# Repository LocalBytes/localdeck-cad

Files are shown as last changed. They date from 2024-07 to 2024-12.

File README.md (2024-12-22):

# LocalDeck CAD

## About

This is the repo for the LocalDeck CAD; it is split into multiple parts:

- [freecad](./freecad)
    - Uses FreeCAD v1
    - Contains all of the mechanical CAD resources
    - You should start with [asm-localdeck](./freecad/asm-localdeck.FCStd)
- [kicad](./kicad)
    - Uses Kicad v8
    - Contains all of the electrical CAD resources

## Contributing

The best way to contribute to the LocalDeck (and it's configurator) is by using the development version in your HomeAssistant, and reporting any issues you find.
Additionally, we would appreciate it if you were to be active on the Forum should we solicit feedback on a new feature or change.

We do not recommend pull-requests to this repo. Git doesn't handle CAD files too well.
If you are a mechanical or electrical engineer, the best way to contribute would be by opening 
If you are a developer, you can also contribute by submitting a pull request to this repository. Please be aware that any code contributed will become the property of Allport-IT LTD.

## Licence
This project is currently published with no specific licence:
- This program is distributed in the hope that it will be useful,
  but WITHOUT ANY WARRANTY
- As an individual user, you are free learn from it, and use it in your own projects
- You must not claim it as your own

Unless otherwise stated, all code is &copy; Allport-IT LTD. All rights reserved.  
"LocalBytes" and the LocalBytes Logo are &reg; of Allport-IT LTD.

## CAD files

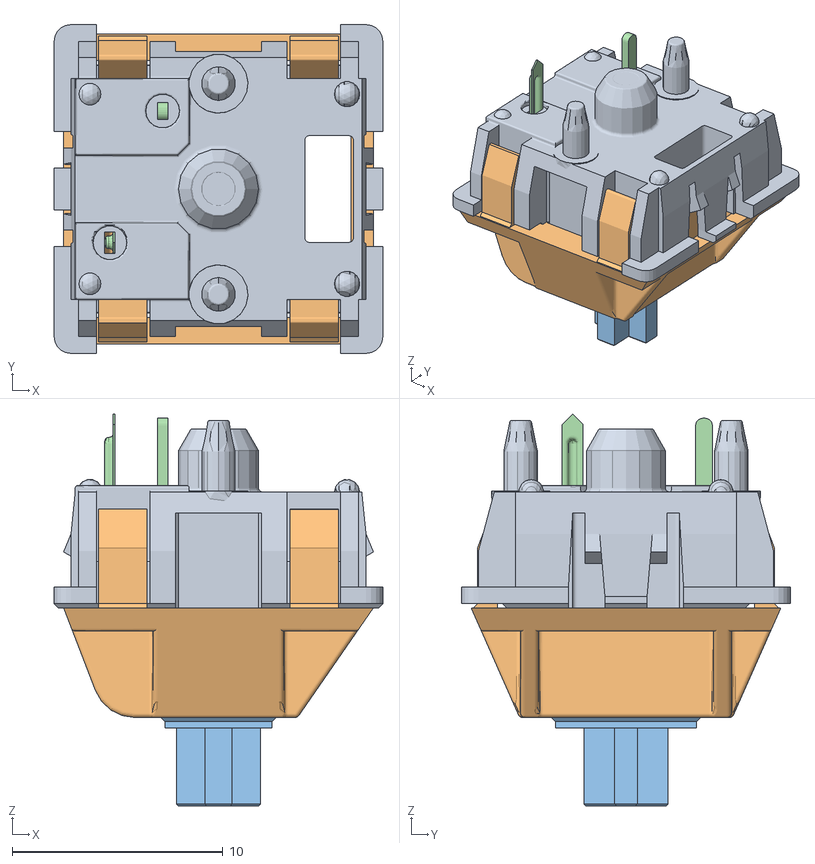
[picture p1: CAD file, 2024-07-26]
freecad/parts/subparts/asm_mx_asm_PCB.obj
15.6 x 15.6 x 18.6

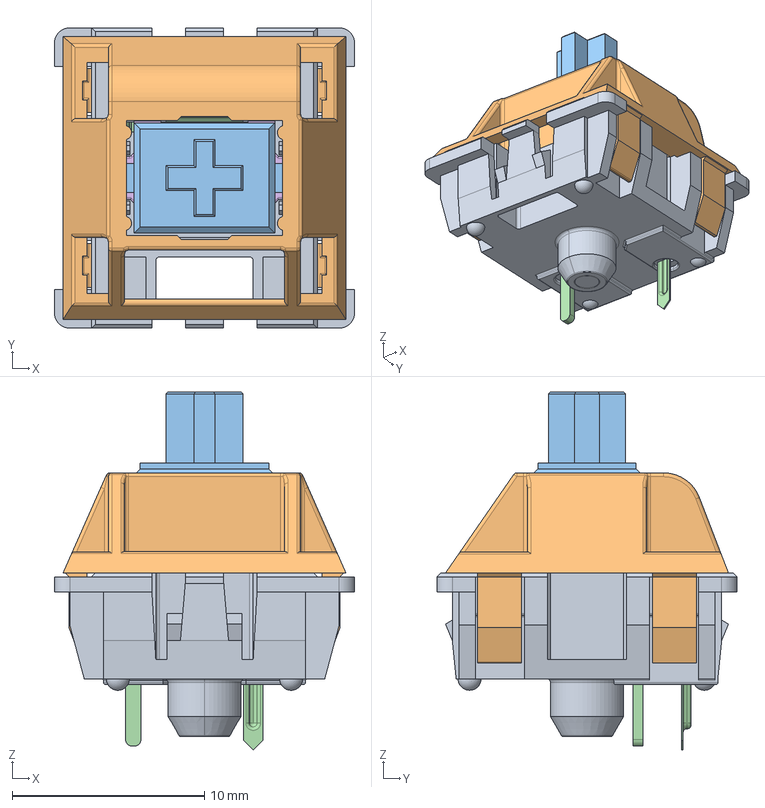
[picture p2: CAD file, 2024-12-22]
freecad/asm-key.FCStd
15.6 x 15.6 x 18.6 mm
MX_DOWN
MX_UP
UP_MX
MX_PIN
MX_SPRING
MX_CLICK

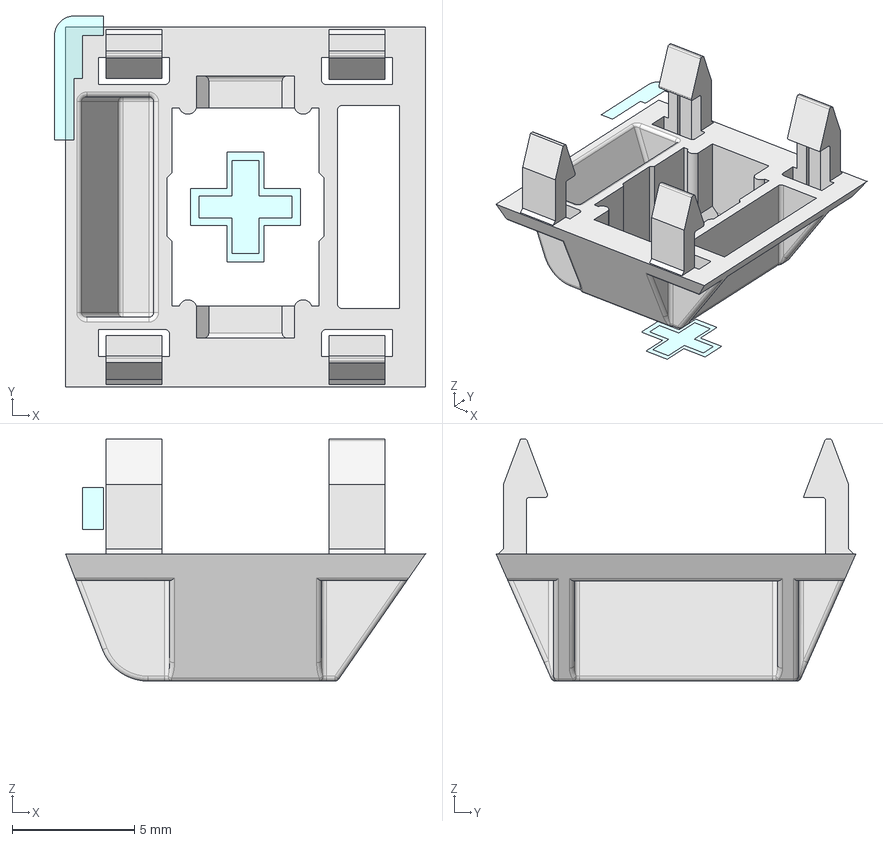
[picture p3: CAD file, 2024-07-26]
freecad/asm-switch.FCStd
15.2 x 15.1 x 14.1 mm
Element002
Element003
MX_UP
_Element
_Element001

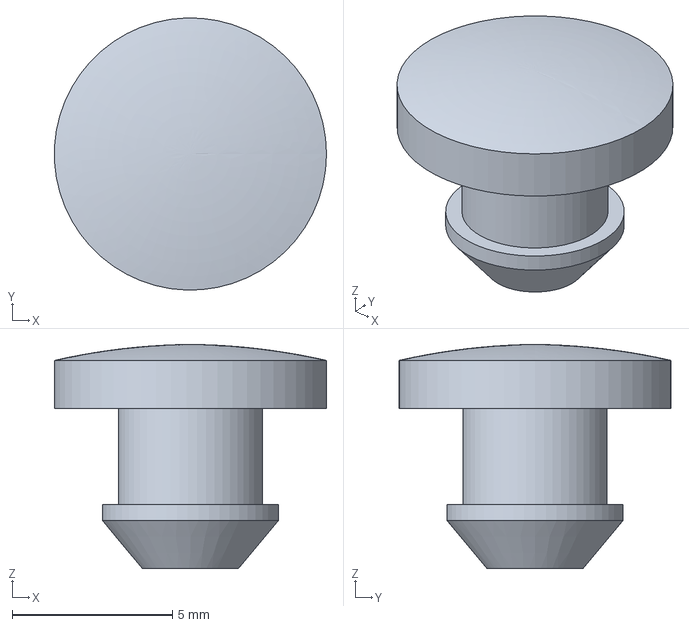
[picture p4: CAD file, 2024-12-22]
freecad/part-cap-A4.5.FCStd
8.49 x 8.50 x 7.00 mm

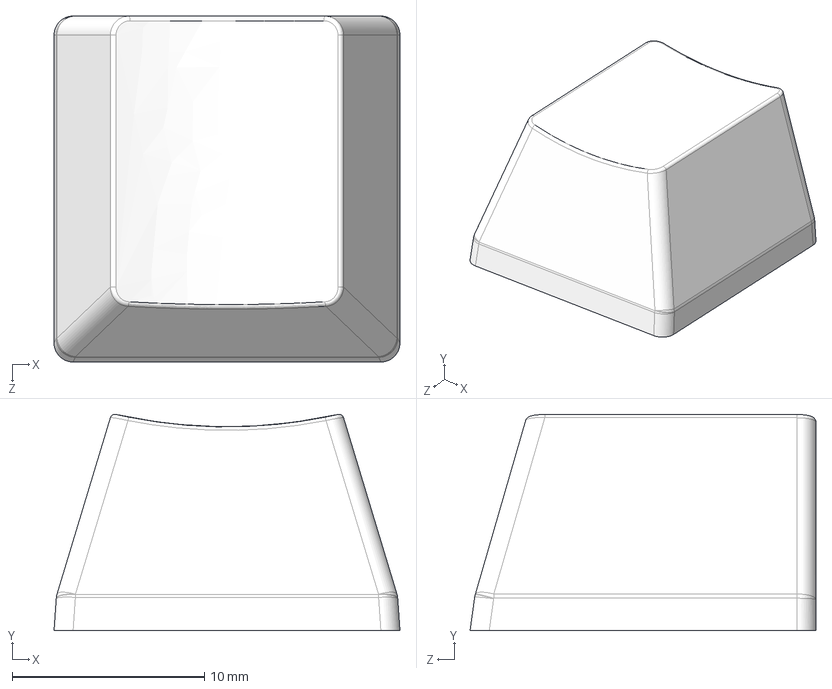
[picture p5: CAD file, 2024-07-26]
freecad/parts/MX-cap.STEP
18.0 x 11.3 x 18.0 mm

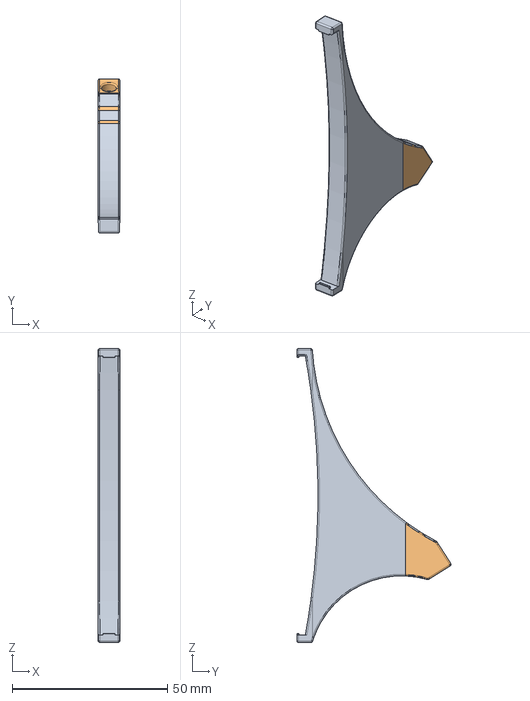
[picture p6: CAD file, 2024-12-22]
freecad/part-stand.FCStd
7.00 x 49.8 x 94.8 mm
stand
SectionCutY

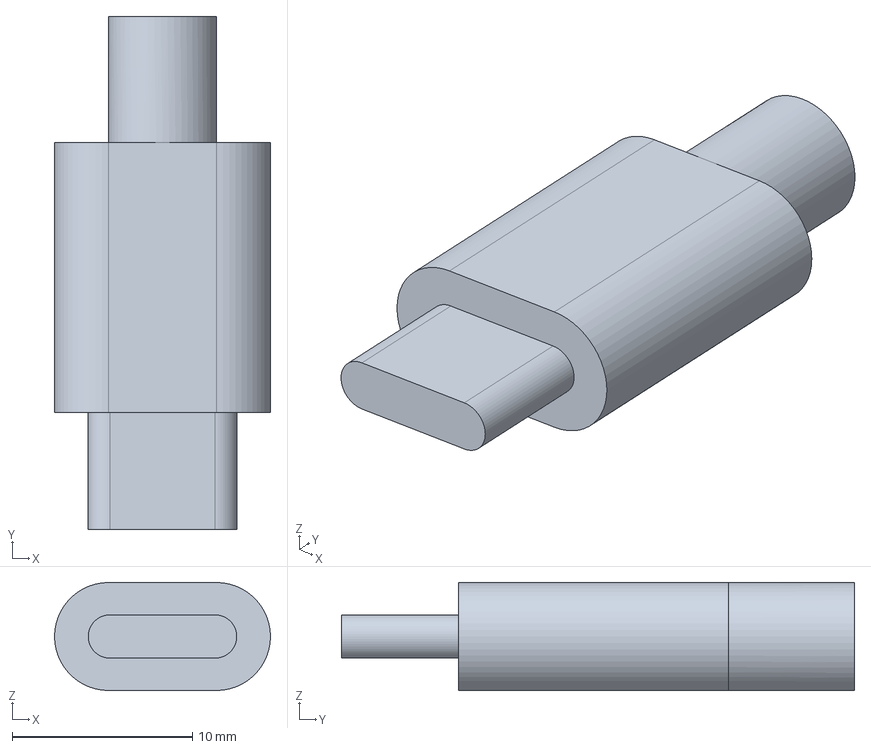
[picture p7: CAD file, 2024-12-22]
freecad/part-usb-plug.FCStd
12.0 x 28.5 x 6.00 mm

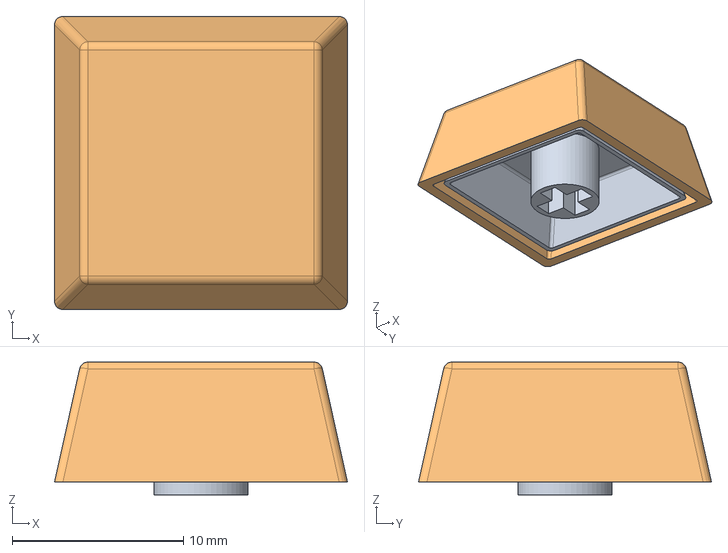
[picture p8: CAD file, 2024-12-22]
freecad/part-key-cap.FCStd
17.1 x 17.1 x 7.75 mm
Cap
Cover

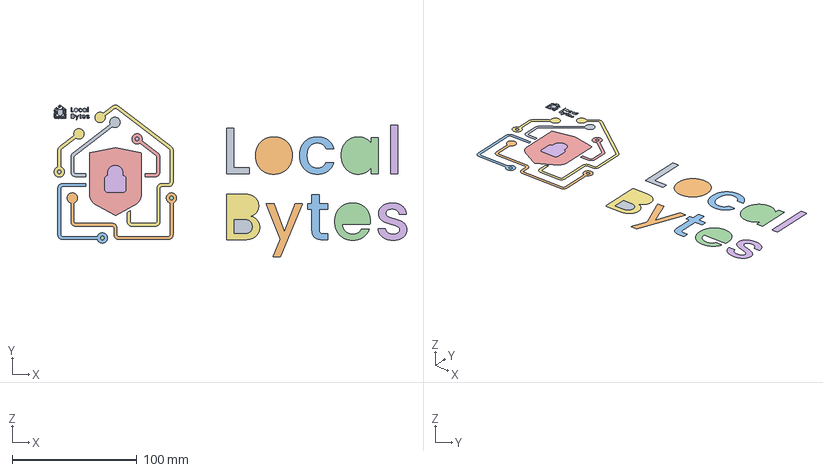
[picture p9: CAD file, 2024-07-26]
freecad/part-logo.FCStd
282.7 x 121.7 x 0 mm
Path
Path001
Path003
Path004
Path005
Path006
Path007
Path008
Path009
Path010
Path011
Path012
Path013
Path014
Path015
Path016
Path017
Path018
Path019
Path020
Path021
Path022
Path023
Path024
Path025
Path026
Path027
Path028
Path029
Path030
Path031
Path002
Path032

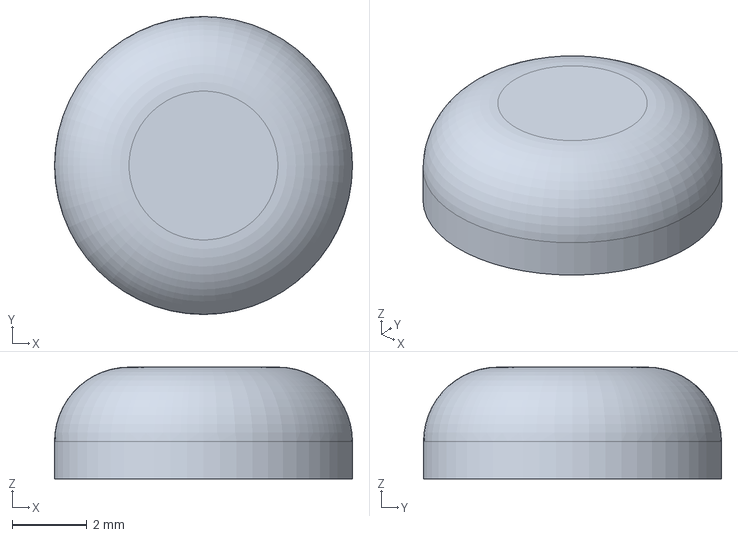
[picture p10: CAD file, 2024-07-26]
freecad/part-anti-slip.FCStd
8.00 x 8.00 x 3.00 mm

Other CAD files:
freecad/parts/asm_mx_asm_PCB.stp
freecad/parts/asm_mx_asm_PLATE.stp
freecad/asm-localdeck.FCStd
freecad/part-pcb.FCStd

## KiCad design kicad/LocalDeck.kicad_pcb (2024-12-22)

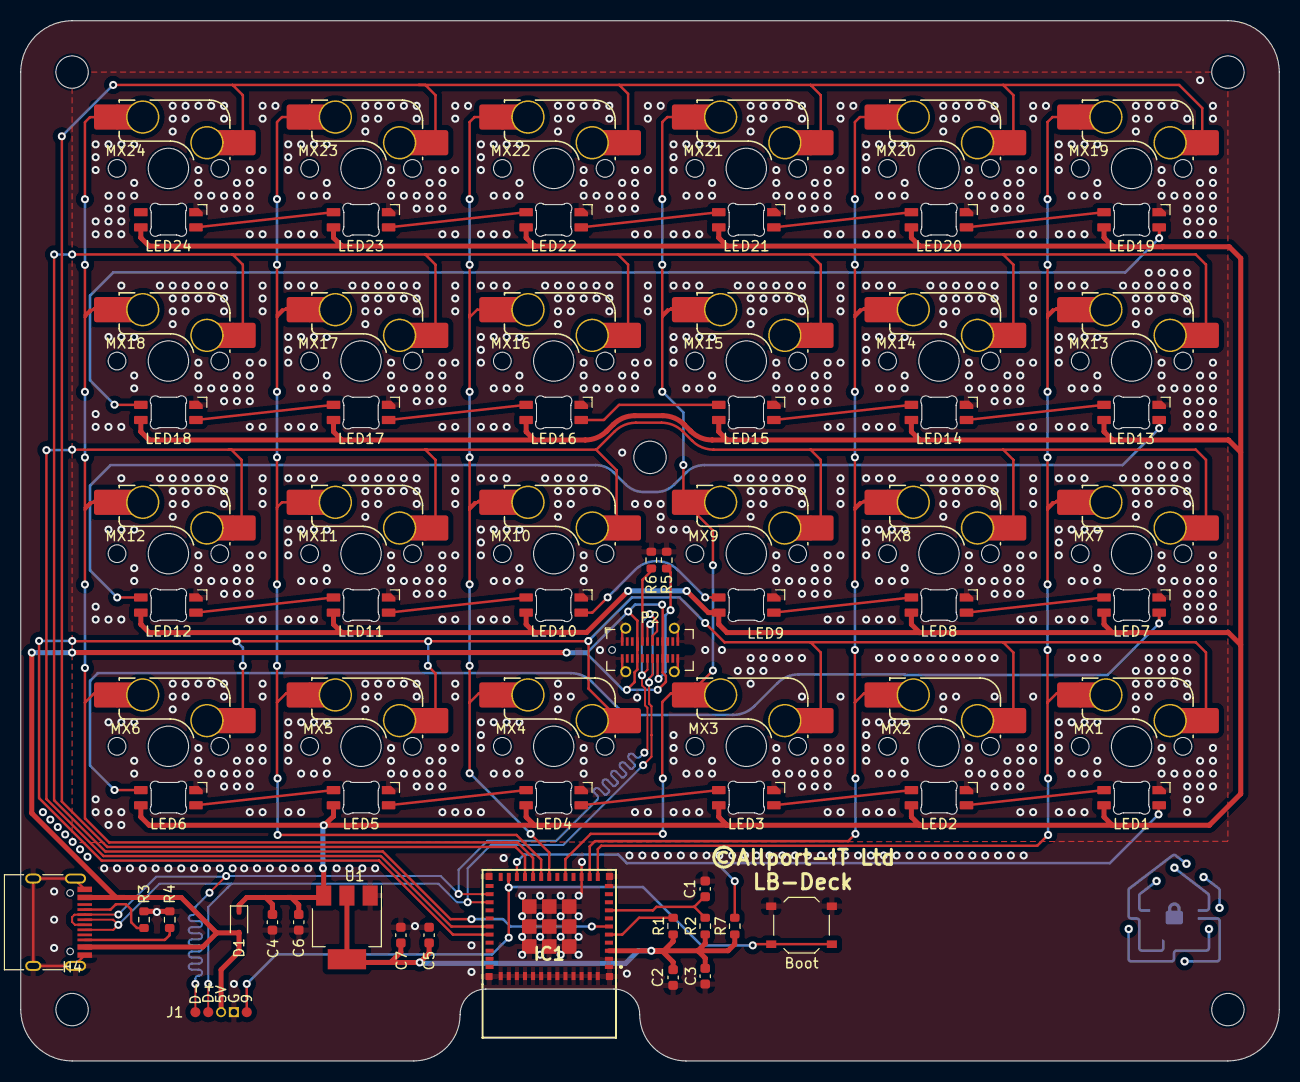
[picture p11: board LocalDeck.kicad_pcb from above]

Board: 2 copper layers, 124.5 x 102.9 mm, 74 parts (0 on the bottom side), 47 nets.

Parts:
C1: 1uf; C_0603_1608Metric
C2, C4: 10uf; C_0603_1608Metric
C3, C6, C7: 0.1uf; C_0603_1608Metric
C5: 22uf; C_0603_1608Metric
D1: BAT60A; D_SOD-323
H1, H2, H3, H4, H5: MountingHole; MountingHole_3.2mm_M3
IC1: ESP32-C3-MINI-1-N4; ESP32C3MINI1N4
J1: Conn_Prog; ProgrammingHeader
LED1, LED2, LED3, LED4, LED5, LED6, LED7, LED8, LED9, LED10, LED11, LED12, LED13, LED14, LED15, LED16, LED17, LED18, LED19, LED20, LED21, LED22, LED23, LED24: MX_SK6812MINI-E; LED_MX_6028R-ROT
MX1, MX2, MX3, MX4, MX5, MX6, MX7, MX8, MX9, MX10, MX11, MX12, MX13, MX14, MX15, MX16, MX17, MX18, MX19, MX20, MX21, MX22, MX23, MX24: MX_SW_HS; SW_MX_HS_1u
P1: USB_C_Receptacle_USB2.0; USB_C_Receptacle_HRO_TYPE-C-31-M-12
P2: USB_C_Receptacle_USB2.0; USB_C_Receptacle_GCT_USB4115-03-C
R1, R2, R7: 10k; R_0603_1608Metric
R3, R4, R5, R6: 5k; R_0603_1608Metric
SW1: Boot; SW_Push_1P1T_XKB_TS-1187A
U1: AMS1117-3.3; SOT-223-3_TabPin2

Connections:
+3.3V: C2.2, C3.2, C5.1, C7.1, IC1.3 (3V3), R1.1, R2.1, R7.2, U1.2 (VO)
+5V: C4.1, C6.1, D1.1 (K), LED1.1 (VDD), LED2.1 (VDD), LED3.1 (VDD), LED4.1 (VDD), LED5.1 (VDD), LED6.1 (VDD), LED7.1 (VDD), LED8.1 (VDD), LED9.1 (VDD), LED10.1 (VDD), LED11.1 (VDD), LED12.1 (VDD), LED13.1 (VDD), LED14.1 (VDD), LED15.1 (VDD), LED16.1 (VDD), LED17.1 (VDD), LED18.1 (VDD), LED19.1 (VDD), LED20.1 (VDD), LED21.1 (VDD), LED22.1 (VDD), LED23.1 (VDD), LED24.1 (VDD), U1.3 (VI)
/USB_D+: IC1.27 (IO19), J1.4, P1.A6 (D+), P1.B6 (D+), P2.A6 (D+), P2.B6 (D+)
/USB_D-: IC1.26 (IO18), J1.5, P1.A7 (D-), P1.B7 (D-), P2.A7 (D-), P2.B7 (D-)
/col0: IC1.12 (IO0), MX1.2, MX7.2, MX13.2, MX19.2
/col1: IC1.13 (IO1), MX2.2, MX8.2, MX14.2, MX20.2
/col2: IC1.16 (IO10), MX3.2, MX9.2, MX15.2, MX21.2
/col3: IC1.18 (IO4), MX4.2, MX10.2, MX16.2, MX22.2
/col4: IC1.19 (IO5), MX5.2, MX11.2, MX17.2, MX23.2
/col5: IC1.20 (IO6), MX6.2, MX12.2, MX18.2, MX24.2
/esp_boot: IC1.23 (IO9), J1.1, SW1.2
/esp_en: C1.1, IC1.8 (EN), R2.2
/led: IC1.22 (IO8), LED1.3 (DIN), R7.1
/row0: IC1.31 (TXD0), MX1.1, MX2.1, MX3.1, MX4.1, MX5.1, MX6.1
/row1: IC1.30 (RXD0), MX7.1, MX8.1, MX9.1, MX10.1, MX11.1, MX12.1
/row2: IC1.6 (IO3), MX13.1, MX14.1, MX15.1, MX16.1, MX17.1, MX18.1
/row3: IC1.21 (IO7), MX19.1, MX20.1, MX21.1, MX22.1, MX23.1, MX24.1
GND: C1.2, C2.1, C3.1, C4.2, C5.2, C6.2, C7.2, IC1.1 (GND_1), IC1.2 (GND_2), IC1.11 (GND_3), IC1.14 (GND_4), IC1.36 (GND_5), IC1.37 (GND_6), IC1.38 (GND_7), IC1.39 (GND_8), IC1.40 (GND_9), IC1.41 (GND_10), IC1.42 (GND_11), IC1.43 (GND_12), IC1.44 (GND_13), IC1.45 (GND_14), IC1.46 (GND_15), IC1.47 (GND_16), IC1.48 (GND_17), IC1.49 (GND_18), IC1.50 (GND_19), IC1.51 (GND_20), IC1.52 (GND_21), IC1.53 (GND_22), IC1.54 (GND_23), IC1.55 (GND_24), IC1.56 (GND_25), IC1.57 (GND_26), IC1.58 (GND_27), IC1.59 (GND_28), IC1.60 (GND_29), IC1.61 (GND_30), J1.2, LED1.4 (VSS), LED2.4 (VSS), LED3.4 (VSS), LED4.4 (VSS), LED5.4 (VSS), LED6.4 (VSS), LED7.4 (VSS), LED8.4 (VSS), LED9.4 (VSS), LED10.4 (VSS), LED11.4 (VSS), LED12.4 (VSS), LED13.4 (VSS), LED14.4 (VSS), LED15.4 (VSS), LED16.4 (VSS), LED17.4 (VSS), LED18.4 (VSS), LED19.4 (VSS), LED20.4 (VSS), LED21.4 (VSS), LED22.4 (VSS), LED23.4 (VSS), LED24.4 (VSS), P1.A1 (GND), P1.A12 (GND), P1.S1 (SHIELD), P2.A1 (GND), P2.A12 (GND), P2.B1 (GND), P2.B12 (GND), P2.S1 (SHIELD), R3.1, R4.1, R5.1, R6.1, SW1.1, U1.1 (GND)
unnamed: IC1.5 (IO2), R1.2
unnamed: LED1.2 (DOUT), LED2.3 (DIN)
unnamed: LED2.2 (DOUT), LED3.3 (DIN)
unnamed: LED3.2 (DOUT), LED4.3 (DIN)
unnamed: LED4.2 (DOUT), LED5.3 (DIN)
unnamed: LED5.2 (DOUT), LED6.3 (DIN)
unnamed: LED6.2 (DOUT), LED7.3 (DIN)
unnamed: LED7.2 (DOUT), LED8.3 (DIN)
unnamed: LED8.2 (DOUT), LED9.3 (DIN)
unnamed: LED9.2 (DOUT), LED10.3 (DIN)
unnamed: LED10.2 (DOUT), LED11.3 (DIN)
unnamed: LED11.2 (DOUT), LED12.3 (DIN)
unnamed: LED12.2 (DOUT), LED13.3 (DIN)
unnamed: LED13.2 (DOUT), LED14.3 (DIN)
unnamed: LED14.2 (DOUT), LED15.3 (DIN)
unnamed: LED15.2 (DOUT), LED16.3 (DIN)
unnamed: LED16.2 (DOUT), LED17.3 (DIN)
unnamed: LED17.2 (DOUT), LED18.3 (DIN)
unnamed: LED18.2 (DOUT), LED19.3 (DIN)
unnamed: LED19.2 (DOUT), LED20.3 (DIN)
unnamed: LED20.2 (DOUT), LED21.3 (DIN)
unnamed: LED21.2 (DOUT), LED22.3 (DIN)
unnamed: LED22.2 (DOUT), LED23.3 (DIN)
unnamed: LED23.2 (DOUT), LED24.3 (DIN)
unnamed: P1.A5 (CC1), R3.2
unnamed: P1.B5 (CC2), R4.2
unnamed: P2.A5 (CC1), R6.2
unnamed: P2.B5 (CC2), R5.2
VBUS: D1.2 (A), J1.3, P1.A4 (VBUS), P1.A9 (VBUS), P2.A4 (VBUS), P2.A9 (VBUS), P2.B4 (VBUS), P2.B9 (VBUS)

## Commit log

2024-07-26 Inital Commit - Adding everything
    [LocalDeck.kicad_pcb, LocalDeck.kicad_sch, MX-cap.STEP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]
2024-07-30 feat: Added programming Header
    [LocalDeck.kicad_pcb, LocalDeck.kicad_sch, frontpanel.kicad_sch]
2024-07-31 chore: Removed unused part
    [part-backplane-flat.FCStd]
2024-07-31 feat: Made enclosure compatable with new feet
2024-07-31 feat: Updated asm-enclosure to show new feet
    [asm-enclosure.FCStd, part-cap-A4.5.FCStd]
2024-08-07 feat(freecad): Added usb-c part for clearance
    [part-usb-plug.FCStd]
2024-08-07 refactor(freecad): Moved `part-cap` to `part-key-cap`
    [part-key-cap.FCStd]
2024-08-07 feat(freecad): Moved asm-key to Ondsel Assembly
    [asm-key.FCStd, part-key-cap.FCStd]
2024-08-07 feat(freecad): Rebuilt main assembly
    [asm-key.FCStd, asm-localdeck.FCStd, part-cap-A4.5.FCStd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]
2024-08-07 fix: Added more USB Clearance
    [asm-enclosure.FCStd, asm-key.FCStd, asm-localdeck.FCStd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]
2024-08-14 feat(freecad): Added boot hole & stats window
    [asm-localdeck.FCStd]
2024-08-14 chore(kicad): Added measurements & part numbers
    [LocalDeck.kicad_pcb, LocalDeck.kicad_sch]
2024-08-18 chore: Latest FCad version, previous didn't calculate suptractive patterns properly!
    [asm-key.FCStd, asm-localdeck.FCStd, part-cap-A4.5.FCStd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]
2024-12-22 chore: FreeCAD 1.0.0
    [LocalDeck.kicad_pcb, asm-key.FCStd, asm-localdeck.FCStd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]
